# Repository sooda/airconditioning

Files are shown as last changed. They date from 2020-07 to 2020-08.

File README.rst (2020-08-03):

my air conditioning adapters
============================

You probably won't need any of these highly specific 3D print designs.

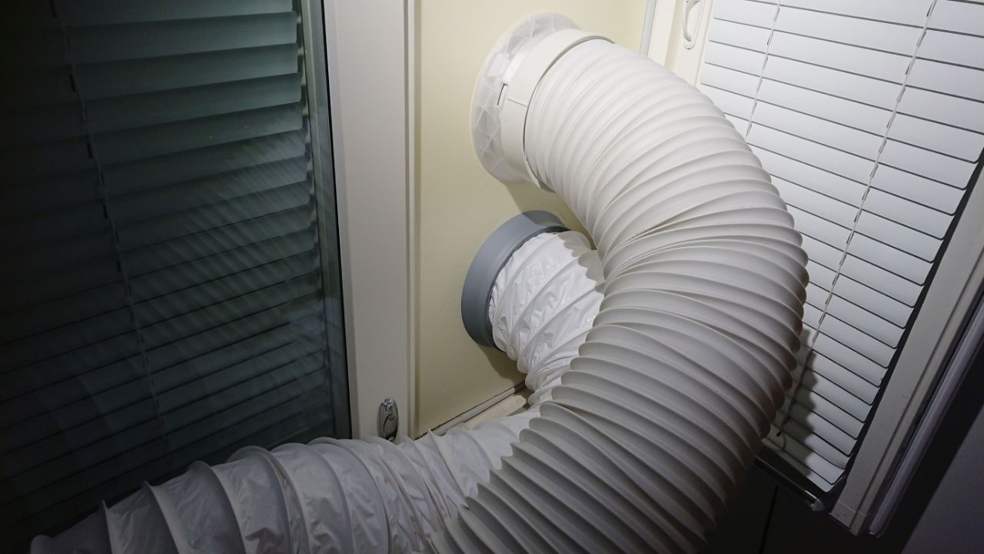
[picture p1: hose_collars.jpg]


Procedure
---------

0. Suffer from 27+ °C indoors
1. Overthink those poor portable AC units
2. Buy one that seems decent from the internets
3. The delivery service destroys it
4. All decent ones are sold out because it's spring already
5. Get angry, lose interest
6. Buy a cheapo model from the nearest hardware store
7. Overthink a window attachment for its hose(s), buy some XPS sheet for a tight window fit
8. Hack up an intake hose connection out of cardboard and hose stuff from a hardware store
9. 3D print neat attachments for the hose ends for easier use
10. Document it so I'll remember later what has happened

TODO
~~~~

* Optimize: find where air is leaking, insulate the hoses, etc.
* Finish the outdoor parts to keep rain out.
* Hack up something on the cool air vent to shoot the air at an adjustable angle so the machine could be placed more conveniently in a corner.
* Buy a house or something to avoid this workaround shit in the first place.

exhaust_adapter.scad
--------------------

Adapts the exhaust hose end to the window panel.
The exhaust hose has proper plastic attachments on obviously the machine end and also on the window end, although the box didn't include any information on how to use that.

I've fitted a mosquito net separately on the whole window, so this piece doesn't have any filter things for when the device is off and no air is moving.
The inner pipe is supposed to be glued to a flap mechanism that doesn't exist yet to protect from heavy rain.
I'll get to that later.

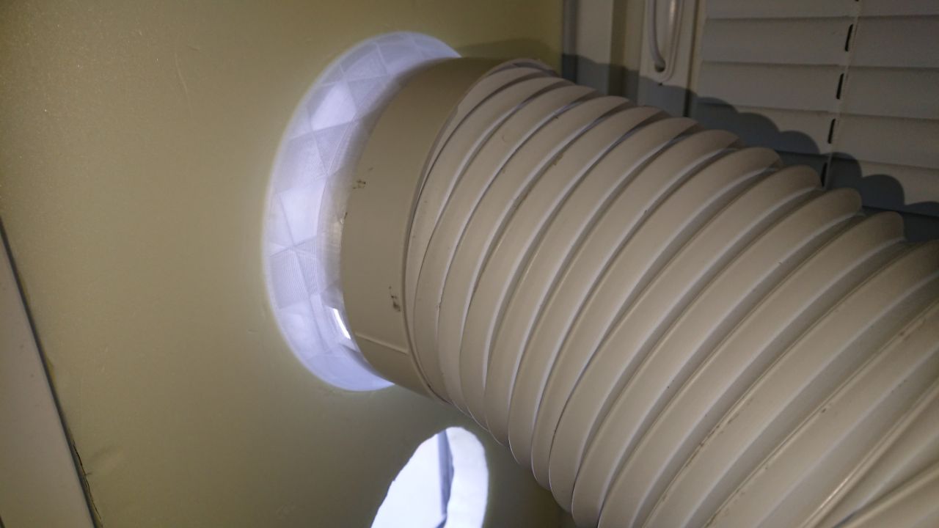
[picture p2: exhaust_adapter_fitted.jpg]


input_screw_flange.scad
-----------------------

Adapts the DIY input hose to the the box thing that's around the large rectangular intake of the hot side.
The intake grille is way too big for 3d printing but easy-shaped so that just a cardboard adapter to another adapter is good enough.
The hose screws inside this printed part that is then attached on the cardboard box.

Fortunately the device appears to have separate air circuits for the hot side and the cold side, so it's possible to add an input hose to match the hot output.
This way the device at least won't unbalance the indoor air pressure and airflow so much and won't heat and push out the cooled indoor air.
I haven't measured whether this makes a big difference.

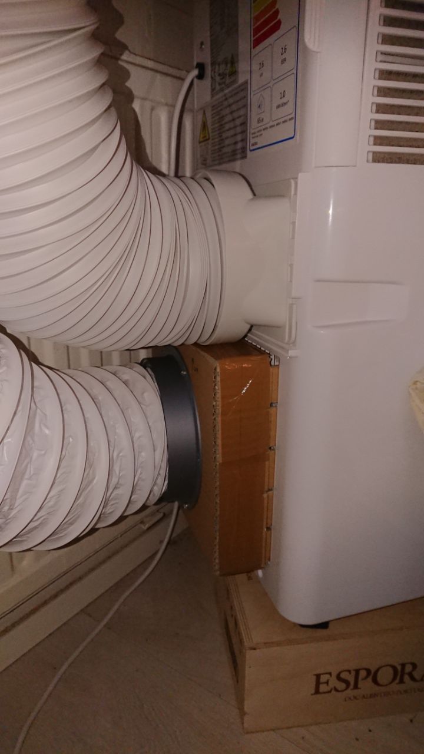
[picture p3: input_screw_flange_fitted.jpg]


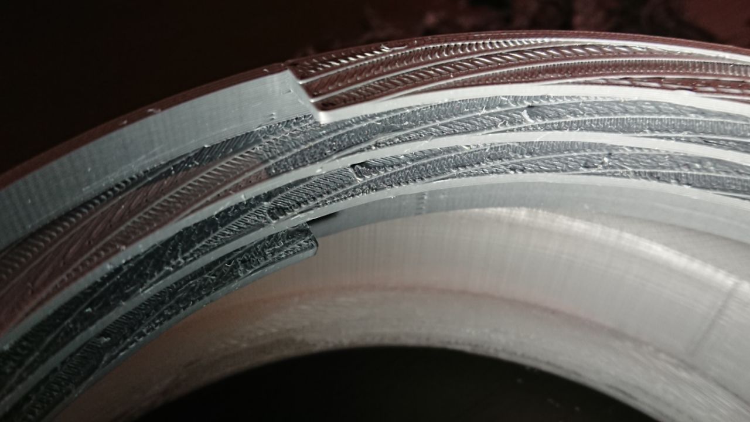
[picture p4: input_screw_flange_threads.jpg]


input_hose_collar.scad
----------------------

Like the side on the machine input, this screws on the `biltema hose`_ but on the other end that goes on the window panel like the exhaust adapter.
This is not an extra adapter but goes directly on the window panel.
The inner part is again supposed to be glued to a flap mechanism or something, see the exhaust_adapter story.

.. _biltema hose: https://www.biltema.fi/rakentaminen/lvi/ilmanvaihto/ilmanvaihtoletkut/ilmanvaihtoletku-2000031439

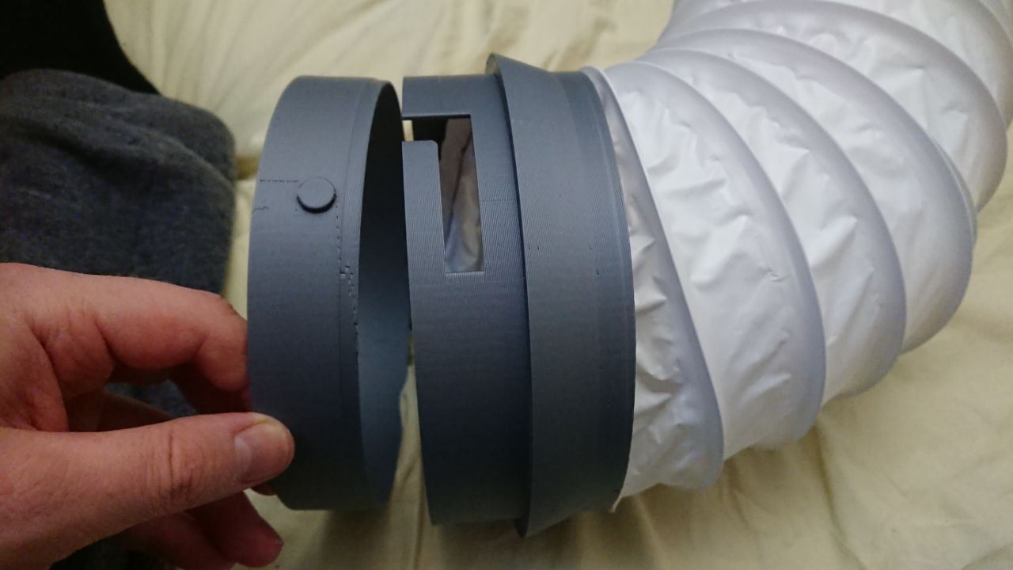
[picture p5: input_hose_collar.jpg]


The device
----------

Bought from here: https://www.motonet.fi/fi/tuote/789629/Ilmastointilaite-siirrettava-9000-BTU

It's apparently Chinanordica A007G-09C: http://chinanordica.com/portableairconditioner_215.html

Kinda works but it's terrible.

License
-------

`CC-BY-SA 4.0 <https://creativecommons.org/licenses/by-sa/4.0/>`_ - tl;dr: share and adapt, just say where it's from and what you changed, and keep these conditions.

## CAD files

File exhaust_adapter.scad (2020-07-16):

// the connector adapter
render_hose_part = true;
// use this to check alignment
hose_translucent = true;
// the rain filter
render_outdoor_part = true;
// render the full pipe, turn off to see the lock parts
show_body = true;
// model the tooth notch receptable as cylinder geometry, not cube
accurate_tooth = true;

// measurements of the existing hose attachment:

// the collar where the hose screws into
outer_length = 30;
// outermost dimension
outer_diameter = 152; // 151...152.8
// not inside the connector, but the outer part of the smaller bit that goes inside this adapter
inner_diameter = outer_diameter - 2 * 4.4;
// from the outer bit to the lock tooth lip with some margin
lock_tooth_notch_depth = 2.2;
// the tooth is a slope, this is the nonzero end measured against inner_diameter
lock_tooth_thickness = 1.7;
// some margin so the locks don't need to be pushed all the way
lock_tooth_ease = 0.5 * lock_tooth_thickness;
// lock tooth size in the radial direction
tooth_width = 20;
// basically pipe_overlap - lock_tooth_notch_depth
tooth_height = 10;
// length of the smaller bit
pipe_overlap = 12.6;

// general body sizes:

// this adapter goes to a panel that replaces one of my window frames for the summer
// the previous hack had a 16cm hose and this goes to the same cutout
panel_hole_diameter = 160;
// the pipe goes through the panel
panel_thickness = 30;
// a flange bit to keep the part close to the panel; "radius" dimension
collar_width = 7;
// the collar bit aesthetic length between outer_diameter and panel_hole_diameter; like this for symmetry
collar_length = outer_length - pipe_overlap;
// before the collar, goes around the pipe_overlap bit with inner_diameter
// XXX: this is a bad name
pipe_full_length = pipe_overlap;//outer_length - collar_length;

// the "outdoor" side part that will have flaps of some sort to block rain:

// how much to reserve outside the panel hole to glue to the actual flap mechanism
flappipe_joinlength = 2;
// this goes inside the hose attachment adapter
flappipe_length = panel_thickness + flappipe_joinlength;
// doesn't need to be very heavy, just smooth. XXX: quantize according to your 3d printer nozzle
flappipe_thickness = 4;
// the inner diameter is consistent throughout the parts
flappipe_outer_diameter = inner_diameter + 2 * flappipe_thickness;

// the two pipes lock together slightly to ensure consistency:

// groove depth into the flap pipe. XXX: quantize according to your 3d printer nozzle
lockring_depth = 2;
// the two parts will rotate and clip on together; this is measured against the indoor end of the outdoor pipe
lockring_length = 2;
// length and some extra slop; XXX: quantize
lockring_groove_clearance = 0.2;
// consistent dimensions just with slop
lockring_groove = lockring_length + lockring_groove_clearance;
// how far the snap knob is from the end of the latch head, measured along the inner_diameter surface
lockblob_distance = 8;
// multiplier for how much bigger the notch is than the blob
lockblob_clearance = 1.05;
// how long the lock mechanism is around the cylinder surface
lockring_length_angle = 45;

// debug and dev stuff:

// use this to lift the inner bit out for debugging
parts_shift = 0;
//parts_shift = 1.5 * panel_thickness;

// angle for visual debugging of the lock knob
lockviz_delta = 0;

// fight the z with 1% the feature size
eps = 0.01;
// very long
inf = 1000;

include <utils.scad>

// a positive geometry to reduce from the indoor pipe body
module lock_notch_receptable() {
	if(!accurate_tooth) {
		// fast mode
		translate([0, -tooth_width / 2, 0]) {
			translate([0, 0, lock_tooth_notch_depth]) {
				// the hole bit
				cube([outer_diameter / 2 + eps, tooth_width, tooth_height]);
			}
			translate([0, 0, -eps]) {
				// the ease bit measured from the floor of the pipe
				cube([inner_diameter / 2 + lock_tooth_ease + eps, tooth_width, tooth_height]);
			}
		}
	} else {
		// this way makes the preview extremely slow, and buggy depending on the view angle and the
		// below choices, or makes the whole design disappear. The render will be fine though. I'll
		// debug why some day. Might be a bug/feature with the huge boxes in the pizza pipe.
		// Swap the inner true to false to use pizza pipes and the whole preview vanishes.

		if (true) translate([0, 0, lock_tooth_notch_depth]) {
			// the hole bit
			if (true) {
				pizzaslice(tooth_height,
					outer_diameter / 2 + eps,
					angle_for_circumference(tooth_width, inner_diameter / 2));
			} else {
				pizzapipe(tooth_height,
					outer_diameter / 2 + eps,
					inner_diameter / 2 - eps,
					angle_for_circumference(tooth_width, inner_diameter / 2));
			}
		}
		if (true) translate([0, 0, -eps]) {
			// the ease bit measured from the floor of the pipe
			if (true) {
				pizzaslice(lock_tooth_notch_depth + 2*eps,
					inner_diameter / 2 + lock_tooth_ease,
					angle_for_circumference(tooth_width, inner_diameter / 2));
			} else {
				pizzapipe(lock_tooth_notch_depth + 2*eps,
					inner_diameter / 2 + lock_tooth_ease,
					inner_diameter / 2 - eps,
					angle_for_circumference(tooth_width, inner_diameter / 2));
			}
		}
	}
}

// the indoor side of the pipe locking mechanism
module latchpin(angle) {
	translate([0, 0, lockring_length + lockring_groove_clearance / 2]) {
		// rotate away from the stop bit
		rotate([0, 0, angle - angle_for_circumference(lockring_length, inner_diameter / 2)]) {
			difference() {
				// the pin itself. The added epsilon gets rid of flickering that supposedly comes
				// from the pin pizza CSGing exactly against the pipe surface; although it's a
				// separate operation, it gets visible and might cause some nasty zero-size
				// geometry? Again, it would be nice to be able to constraint this on exactly the
				// inner surface, but here we are with floating point math.
				pizzapipe(lockring_length,
						flappipe_outer_diameter / 2 + eps,
						flappipe_outer_diameter / 2 - lockring_depth,
						lockring_length_angle);
				// the lock notch cut away from the pin
				rotate([0, 0, lockring_length_angle
						- angle_for_circumference(lockblob_distance - lockring_length, inner_diameter / 2)]) {
					// FIXME: make some of the geometry common for the pin and the groove
					translate([flappipe_outer_diameter / 2 - lockring_depth, 0, -eps]) {
						cylinder(h=lockring_length + 2*eps,
							r=lockblob_clearance * lockring_depth / 2,
							$fs=0.1);
					}
				}
			}
		}
	}
}

// the outdoor side of the pipe locking mechanism
module lockslider(angle) {
	translate([0, 0, eps]) // fuck that flicker and wrong colors on surfaces
	rotate([0, 0, angle]) {
		// the slider including the end stop
		difference() {
			// yes, +eps. This ensures the surface goes inside the other
			pizzapipe(lockring_length + lockring_groove + eps,
					flappipe_outer_diameter / 2,
					flappipe_outer_diameter / 2 - lockring_depth - eps,
					lockring_length_angle);
			// the pin groove is a bit higher and offset for the stop
			rotate([0, 0, -angle_for_circumference(lockring_length, inner_diameter / 2)]) {
				translate([0, 0, lockring_length]) {
					pizzapipe(lockring_groove + 2 * eps,
						flappipe_outer_diameter / 2 + eps,
						flappipe_outer_diameter / 2 - lockring_depth - 2 * eps,
						lockring_length_angle);
				}
			}
		}
		// the lock blob
		rotate([0, 0, lockring_length_angle
				- angle_for_circumference(lockblob_distance, inner_diameter / 2)]) {
			translate([flappipe_outer_diameter / 2 - lockring_depth, 0, lockring_length]) {
				cylinder(h=lockring_groove, r=lockring_depth / 2, $fs=0.1);
			}
		}
	}
}

module hose_part() {
	if (show_body) {
		color("yellow") {
			// Change this difference to union to debug the slow rendering
			difference() {
				pipe(pipe_full_length, outer_diameter / 2, inner_diameter / 2);
				render()
				union() {
					lock_notch_receptable();
					rotate([0, 0, 360/3])
						lock_notch_receptable();
					rotate([0, 0, 2*360/3])
						lock_notch_receptable();
				}
			}
			// the collar goes from the interface bit to the face of the panel.
			// why does the epsilon trick not help here with that hot pixel flicker on the inner face?
			translate([0, 0, pipe_full_length - eps])
				pipe_outer_bevel(eps + collar_length,
					outer_diameter / 2,
					panel_hole_diameter / 2 + collar_width,
					inner_diameter / 2);
			// the bit inside the panel. The inner diameter grabs to the outdoor pipe
			translate([0, 0, pipe_full_length + collar_length - eps])
				pipe(eps + panel_thickness,
					panel_hole_diameter / 2,
					flappipe_outer_diameter / 2);
		}
	}

	color("blue") {
		// note: no stop ring needed - the panel part is larger inside to fit the outdoor pipe
		translate([0, 0, pipe_full_length + collar_length]) {
			// the latch pins hover above the stop ring
			latchpin(0);
			latchpin(180);
		}
	}
}
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

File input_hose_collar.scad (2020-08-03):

// #87-3828 152mm 3m air hose:
// https://www.biltema.fi/rakentaminen/lvi/ilmanvaihto/ilmanvaihtoletkut/ilmanvaihtoletku-2000031439

// This piece goes directly through the window panel! The two-piece construction on the exhaust hose
// is just to match and reuse the existing collar on it.

// the collar itself
render_hose_part = true;
// use this to check alignment and to debug the threads
hose_translucent = true;
// the rain filter
render_outdoor_part = true;

// outmost hose dimensions, by chance it's the same as the outer diameter of the exhaust hose collar
hose_outer_diameter = 152;
// gap between the hose and the inner face of the pipe
thread_tolerance = 2;
// 160 mm matches the other window panel hole and thickness becomes 2 mm
outer_diameter = 160;

// the outer dimension is more important than this one, although do mind this as well
thickness = (outer_diameter - hose_outer_diameter) / 2 - thread_tolerance;

// this much overlap with the hose
visible_length = 30;

// the pipe goes through the panel and an outdoor part aligns with this inner face
panel_thickness = 30;
// a flange bit to keep the part close to the panel; "radius" dimension
collar_width = 7;
// The collar overlaps with the threaded bit and is this long before reaching the window panel face. Some flat is left for better finger grip
collar_length = 20;

// keep this less than ~17mm
thread_depth = 8;
// thread face dimension on the visible (hose) side. A trapezoidal cross section may cause your slicer to generate a more complex thread surface that will slide easier but is a pain to clean up from the supports.
thread_thickness_side = 1.5;
// thread face dimension on the pipe side
thread_thickness_body = 3;
// spacing between facing thread faces to contribute to the lead aka pitch, compare against the hose flex
thread_spacing = 4;
thread_lead = thread_thickness_body + thread_spacing;
// Three shall be the number thou shalt count, and the number of the counting shall be three.
thread_revolutions = 3;

thread_length = thread_lead * thread_revolutions;

inner_diameter = hose_outer_diameter + 2 * thread_tolerance;
thread_inner_diameter = inner_diameter - 2 * thread_depth;

// how much to reserve outside the panel hole to glue to the actual flap mechanism
flappipe_joinlength = 2;
// this goes inside the hose attachment adapter
flappipe_length = panel_thickness + flappipe_joinlength;
// doesn't need to be very heavy, just smooth
flappipe_thickness = 2;
// there has to be some slop so the flap pipe that goes inside can be inserted smoothly
flappipe_tolerance = 0.2;
// the inner diameter is NOT consistent throughout the parts because the outer body is so thin
flappipe_outer_diameter = inner_diameter - 2 * flappipe_tolerance;
flappipe_inner_diameter = flappipe_outer_diameter - 2 * flappipe_thickness;
// how much until full thickness
flappipe_bevel_length = 10;
// how much to take off from flappipe_thickness
flappipe_bevel_thickness = 2;

// the knob to join the indoor and outdoor parts is situated in the outdoor border and is this big
lockknob_diameter = 10;
// insertion depth
lockslot_depth = 20;
// "tangential" length along the side
lockslot_length = 30;
// total slop, not in "both sides" like the others here
lockslot_clearance = 0.1;
// "negative" clearance on the edge where the locking action should happen. This tiny fit blob is likely unnecessary, but let's see what happens with it.
lockslot_tightfit = 0.2;

// use this to lift the inner bit out for debugging
parts_shift = 0;
// angle for visual debugging of the lock knob
lockviz_delta = 0;

// fight the z with 1% the feature size
eps = 0.01;
// very long
inf = 1000;

include <utils.scad>

module helix() {
	//     body
	//    ______
	// ^ \      /
	// y  \____/
	// |   side
	// +--x> (not to scale)
	// ccw
	cross_section = [
		[(thread_thickness_body - thread_thickness_side) / 2, 0],
		[(thread_thickness_body - thread_thickness_side) / 2 + thread_thickness_side, 0],
		[thread_thickness_body, thread_depth],
		[0, thread_depth],
	];
	translate([0, 0, 0]) {
		difference() {
			rotate([0, -90, 0]) {
				thread_extrude(cross_section,
					inner_diameter / 2 - thread_depth + 0.05, // XXX: beware of gaps, depends on face count
					thread_length, thread_lead, 360/2);
			}
			// Make the thread tip less blunt by cutting off a slice at an angle. The cut size is
			// chosen for aesthetic reasons to align smoothly to the thread's inner face. The cut
			// begins from the very end and meets the inner face in parallel, forming a 90 degree
			// angle with a line that goes towards the center.
			//
			// This messes up the preview pretty badly depending on the view angle, no clue what
			// that's about.
			//
			// This is also not super general, might not work with very tight threads due to the cut
			// bit being aligned to the very top. These threads are not parallel to the cube face.
			translate([0, 0, -thread_spacing / 2]) {
				// Thanks, Pythagoras
				cut_length = sqrt(pow(inner_diameter / 2, 2) - pow(thread_inner_diameter / 2, 2));
				// law of sines
				cut_triangle_angle = asin(cut_length / (inner_diameter / 2));
				rotate([0, 0, cut_triangle_angle]) {
					cube([
						thread_inner_diameter / 2 + eps,
						thread_inner_diameter / 2,
						thread_thickness_body + thread_spacing]
					);
				}
			}
		}
	}
}

module lockknob_receptable(angle) {
	lockknob_ang = angle_for_circumference(lockknob_diameter + 2 * lockslot_clearance, inner_diameter / 2);
	lockslot_length_ang = angle_for_circumference(lockslot_length, inner_diameter / 2);
	rotate([0, 0, angle - lockknob_ang / 2]) {
		// cut down for the insertion slot
		pizzaslice(lockslot_depth, inf, lockknob_ang);
		difference() {
			// cut along the main cylinder for rotation, ccw for cw locking
			pizzaslice(lockknob_diameter + 2 * lockslot_clearance, inf, -(lockknob_ang + lockslot_length_ang));
			// add back the tiny lock blob. This is not exactly the right position at the end, but
			// doesn't matter, it's close enough, or might not even exist depending on your print slicing.
			rotate([0, 0, -(lockslot_length_ang + 0.25 * lockknob_ang)])
				rotate([0, 90, 0])
					cylinder(h=2*inf, r=lockslot_clearance + lockslot_tightfit, $fn=30);
		}
	}
}

module hose_body() {
	difference() {
		pipe(visible_length + panel_thickness, outer_diameter / 2, inner_diameter / 2);
		translate([0, 0, visible_length + panel_thickness - lockslot_depth + eps]) {
			lockknob_receptable(0);
			lockknob_receptable(180);
		}
	}
	translate([0, 0, visible_length - collar_length]) {
		pipe_outer_bevel(collar_length,
			outer_diameter / 2,
			outer_diameter / 2 + collar_width,
			inner_diameter / 2 + eps);
	}
}

module threaded_body() {
	if (hose_translucent) {
		#hose_body();
	} else {
		hose_body();
	}
	helix();
}

module lockknob(ang) {
	rotate([0, 0, ang]) {
		translate([flappipe_inner_diameter / 2, 0, 0])
		rotate([0, 90, 0]) {
			// XXX: should be a half cone maybe
			cylinder(flappipe_thickness + thickness, r=lockknob_diameter / 2, $fs=0.1);
		}
	}
}

module outdoor_part() {
	// this part is positioned exactly at the panel face
	translate([0, 0, visible_length]) {
		if (true) {
			color("green") {
				difference() {
					pipe(flappipe_length,
						flappipe_outer_diameter / 2,
						flappipe_inner_diameter / 2);
					translate([0, 0, -eps])
					pipe_inner_bevel(flappipe_bevel_length,
						flappipe_outer_diameter / 2 + eps,
						flappipe_outer_diameter / 2 - flappipe_bevel_thickness,
						flappipe_outer_diameter / 2
						);
				}
			}
		}
		color("magenta") {
			translate([0, 0, panel_thickness - 3 * lockknob_diameter / 2]) {
				lockknob(0);
				lockknob(180);
			}
		}
	}
}

module hose_collar() {
	if (render_hose_part)
		threaded_body();
	if (render_outdoor_part)
	translate([0, 0, parts_shift])
		rotate([0, 0, lockviz_delta])
			outdoor_part();
}

hose_collar();

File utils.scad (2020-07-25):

// cylinder minus inner cylinder
module pipe(h, outer_r, inner_r) {
	difference() {
		cylinder(h=h, r=outer_r, $fn=180);
		translate([0, 0, -eps])
			cylinder(h=h+2*eps, r=inner_r, $fn=180);
	}
}

// cone minus inner cylinder
module pipe_outer_bevel(h, outer_r1, outer_r2, inner_r) {
	difference() {
		cylinder(h=h, r1=outer_r1, r2=outer_r2, $fn=180);
		translate([0, 0, -eps])
			cylinder(h=h+2*eps, r=inner_r, $fn=180);
	}
}

// cylinder minus inner cone
module pipe_inner_bevel(h, outer_r, inner_r1, inner_r2) {
	difference() {
		cylinder(h=h, r=outer_r, $fn=180);
		translate([0, 0, -eps])
			cylinder(h=h+2*eps, r1=inner_r1, r2=inner_r2, $fn=180);
	}
}

// a pizza slice is under 90 degrees big and exists in the first quadant, lies on top of the x axis
module pizzamask(angle) {
	intersection() {
		// first quadrant
		translate([0, 0, -inf/2])
			cube([inf, inf, inf]);

		// from x axis counterclockwise
		rotate([0, 0, angle - 90])
			translate([0, 0, -inf/2])
				cube([inf, inf, inf]);
	}
}

// a difference of two of these may glitch in the outer face no matter how big epsilon,
// depending on your gpu driver version?? (in preview mode only)
module pizzapipe(h, outer_r, inner_r, angle) {
	render() // avoid exponential growth
	intersection() {
		pipe(h, outer_r, inner_r);
		pizzamask(angle);
	}
}

module pizzaslice(h, r, angle) {
	render() { // avoid exponential growth
		if (angle < 0) {
			// ccw
			rotate([0, 0, angle]) {
				intersection() {
					cylinder(h=h, r=r, $fn=180);
					pizzamask(-angle + eps);
				}
			}
		} else {
			// cw
			intersection() {
				cylinder(h=h, r=r, $fn=180);
				pizzamask(angle);
			}
		}
	}
}

// for matching pizza slice angles with mm dimensions
// a/360 * 2*pi*r = s
function angle_for_circumference(s, r) = 180 / PI * s / r;

// along x axis, right hand rule
function thread_track_point(r, lead, a) = [
	a / 360 * lead,
	r * cos(a),
	r * sin(a),
];

function thread_track(r, lead, xs) = [
	for (x=xs) thread_track_point(r, lead, x)
];

function rz(a) = [
	[1,      0,       0],
	[0, cos(a), -sin(a)],
	[0, sin(a),  cos(a)]
];

// face_vertices shall be counterclockwise, as it'll be the underside: when
// looking from the top, this grows initially towards the viewer.
module thread_extrude(face_vertices, r, length, lead, rev_resolution) {
	face_size = len(face_vertices);
	revolutions = length / lead;
	// the track with n volume sections has n+1 face segments
	segments = rev_resolution * revolutions + 1;
	//track = thread_track(10, 360, [0:n-1]);
	pts = [
		for (i=[0:segments-1])
			for (p = face_vertices)
				rz(i / rev_resolution * 360) * [p[0], p[1], 0]
						+ thread_track_point(r, lead, i / rev_resolution * 360)
	];

	front_face = [[for (i=[0:face_size-1]) i]];
	back_face = [[for (i=[0:face_size-1]) len(pts) - 1 - i]];
	inner_faces = [
		for (begin_slice = [0:segments-2])
			for (begin_vert = [0:face_size-1]) [
				 begin_slice      * face_size + begin_vert,
				(begin_slice + 1) * face_size + begin_vert,
				(begin_slice + 1) * face_size + (begin_vert + 1) % face_size,
				 begin_slice      * face_size + (begin_vert + 1) % face_size
			]
	];
	faces = concat(front_face, inner_faces, back_face);
	polyhedron(pts, faces);
}

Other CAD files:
input_screw_flange.scad

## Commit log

2020-06-30 initial commit with dimensions and template
    This should fit the connector. The window part does not exist yet.
    [exhaust_adapter.scad]
2020-06-30 pipe it through the panel
    Preparing for a low pressure drop exhaust grille, a 160mm pipe through
    the window frame adapter panel thing. I wonder how the airfoil bits
    should be designed for efficiency. The mosquito net probably kills the
    major part already though.
    [exhaust_adapter.scad]
2020-06-30 collar/flange/something bit to keep this in place
    Something similar to come in the other side too perhaps? Should this
    screw on the panel or just be a tight fit?
    [exhaust_adapter.scad]
2020-07-01 planning on the outdoor side's attachment
    The flaps-side bit shall be a thin pipe to go inside the major body.
    Locking together might happen with a simple mechanism inspired by a dslr
    lens hood.
    [exhaust_adapter.scad]
2020-07-02 receptable for the lock groove
    The other side of the lock mechanism is a pin with a matching slot. Also
    pull the groove parts in so they're properly inside the inner pipe.
    [exhaust_adapter.scad]
2020-07-03 depth stop ring for the inner pipe
    Measurements must be all off-by-one or something at this point. The
    structure is nice enough for now.
    [exhaust_adapter.scad]
2020-07-04 better documentation, restructure
    Shuffle stuff around and rename identifiers for consistency, or else
    I'll go mad in just a day forgetting this. Need to digitize the sketches
    on paper sooner or later, too. Making the outer bit translucent is very
    useful for debugging.
    The lock clearance doesn't seem consistent... A real constraint-based
    CAD with an understanding of surfaces would be so much better for this.
    [exhaust_adapter.scad]
2020-07-04 rotate the whole outer part for visualization
    The latch pins shall be consistent wrt. the whole body
    [exhaust_adapter.scad]
2020-07-05 make outdoor part consistent with inner diameter
    This way the pipe to go inside the panel has a larger inner diameter and
    the "stop ring" appears naturally when the outdoor pipe fills that void.
    [exhaust_adapter.scad]
2020-07-05 careful with epsilons
    Those darn flickering surfaces haunt this design. Always do the epsilon
    on both sides: when translating -eps the size must be inflated by 2*eps.
    [exhaust_adapter.scad]
2020-07-05 so sick of these epsilons
    Preview rendering artifacts make some stuff unusable without epsilons
    because the real render is too slow for iterative development. Some
    flickering still occurs between the pipe segments even with epsilons,
    but it's not a whole surface in the wrong place - just a few pixels.
    [exhaust_adapter.scad]
2020-07-05 give flappipe_outer_diameter a name
    this is the surface between the indoor part and the panel pipe
    [exhaust_adapter.scad]
2020-07-05 make sure the groove fits
    Double checks and clarifications for how the groove is measured. The
    groove with its clearance is the gap where the lock pin goes. The
    outdoor surface shall align exactly with the panel indoor surface.
    [exhaust_adapter.scad]
2020-07-05 model the tooth holes properly but slowly
    So why this is orders of magnitude slower? Something to do with the
    subtraction but really openscad breaks way too easily and it's not
    trivial to figure out what's hogging the cpu all of a sudden.
    [exhaust_adapter.scad]
2020-07-05 from ~6000 to 65 CSG elements
    Prune the normalization tree with a careful render() for the lock notch
    geometry. Those intersecting sectors apparently cause the exponential
    explosion; see commit c810264.
    A general render() in the pizzapipe/pizzaslice ops cause additional z
    fighting.
    https://en.wikibooks.org/wiki/OpenSCAD_User_Manual/FAQ#Why_is_the_preview_so_slow.3F
    "This is hard to explain, but in essence, having intersections as the
    negative objects in difference is expensive"
    Just some thousands of objects doesn't seem so huge though. Perhaps
    someone should fix the immediate mode rendering.
    [exhaust_adapter.scad]
2020-07-05 render also the pizza pipe and slice alreadyo
    Found the cause of the z fighting. It wasn't there before render(). This
    halves the tree size.
    [exhaust_adapter.scad]
2020-07-06 final print settings of v1
    Forgot to save these but the printed object has these dimensions. Also,
    the inner ring is obviously a very tight fit; the lock ring is not even
    needed. Should probably reduce the size by 0.1 mm or so for easier use.
    [exhaust_adapter.scad]
2020-07-14 extract common geometry stuff to utils
    These might be needed with other components as well.
    [exhaust_adapter.scad, utils.scad]
2020-07-14 initial commit for device-side input adapter
    The machine itself does not support an input hose for the hot side but
    it's easily hacked with a cardboard box and some adapters. This will be
    the adapter that goes to the box on the machine's hot-side input hole.
    I've got an annoying hose there already. The better hose I've got is too
    different to fit the existing bits and the shop doesn't stock a matching
    adapter.
    Hey openscad, why no combination of a linear extrude and a rotate
    extrude? Apparently people have made screw libs already but let's make a
    custom one to have some fun. The linear extrude twists in the wrong axis
    for stuff like this and rotate extrude doesn't support z translation.
    [input_screw_flange.scad]
2020-07-14 some screw planning
    Openscad doesn't include a good way to do screw-like things, so let's
    roll our own with a single polyhedron. Coming up with a diy
    rotate_extrude() with extra support to translate along the way would be
    a natural way to do this, or linear_extrude() with the cross section in
    a different angle. Overdoing a general operation to use an extrusion
    track and a cross section must be perfect. Unfortunately functions
    aren't first-class things in the language so a vertex transform function
    won't do.
    [input_screw_flange.scad]
2020-07-14 make the screw work, looking good already
    This appears to work; smoke tested with small resolutions (about 3). Not
    general yet, will fix that later.
    [input_screw_flange.scad]
2020-07-14 move the screw to its proper place
    [input_screw_flange.scad]
2020-07-14 repair fillet
    The rotate-extruded bit has to match the fillet circle accurately enough
    to avoid irregularities far from the vertices.
    [input_screw_flange.scad]
2020-07-14 mounty mcmountface
    This shall be screwed to the cardboard box that is the bigger adapter
    [input_screw_flange.scad]
2020-07-14 bugfix outer diameter
    reference the inner surface with the thickness because tolerance
    [input_screw_flange.scad]
2020-07-14 fix screw winding
    The back face needs a mirrored orientation to be consistent.
    Fix docs: the given face / cross section has to be counterclockwise
    because the screw is constructed that way: when looking at the section
    flat from the z axis, the "back side" of it is seen as it grows that way
    with the right hand rule.
    [input_screw_flange.scad]
2020-07-16 some epsilonification
    now it's no longer invalid.
    This version got printed. Needs improvement on the threads.
    [input_screw_flange.scad]
2020-07-16 fix screw cross section
    Some measurements were of course mirrored accidentally. Use the correct
    ones.
    [input_screw_flange.scad]
2020-07-16 better dimensions for the next input piece version
    - the fit is still pretty tight; add a millimeter to tolerance radius
    - move the mounting holes further apart from the fillet
    - increase mounting hole size by 0.2 mm
    - use six mounting holes just in case as this is such a big object
    - increase the gap between screw surfaces to 4 mm for easier support
    structure cleanup and increased tolerance because the previous was a
    brainfart anyway
    [input_screw_flange.scad]
2020-07-16 readme and stuff for historical reference
    this is easier to share via github than irc and scp
    [exhaust_adapter.scad]
2020-07-23 Final docs on the input flange adapter
    The flanged nut bit for the input hose is now printed. It's not perfect
    but it's fine.
    The threads were a bit tricky to clean up from support material (which
    probably was necessary due to the significant overhang). An even
    side/body thickness for the threads would have mostly prevented this,
    but it would have caused perpendicular steps on the printed layers that
    might interfere with the ease of installation. Probably not though if
    the steel wire inside the hose would be just twisted a bit from the end.
    [input_screw_flange.scad]
2020-07-24 document the nasty thread end for next version
    This particular piece will likely never get a next version, but the
    other end of the hose will have a similar thread. Reminder to update.
    [input_screw_flange.scad]
2020-07-25 s/screw/thread/ in most places
    more exact vocabulary is more exact
    [input_screw_flange.scad]
2020-07-25 make the thread tip less blunt for easier install
    This does not matter anymore for the existing object I have, but the
    other end of the hose will receive the same treatment. Figure out a nice
    triangle from the end tip on the outer thread surface to the side of the
    inner thread surface to meet it tangentially. Use the triangle to cut a
    bit out of the threads.
    Constructing the threads with this "ease-in" built in would be more
    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
    [input_screw_flange.scad]
2020-07-25 move the thread extrusion to utils
    [input_screw_flange.scad, utils.scad]
2020-07-25 initial input hose collar object
    This goes to the other end of the input hose, facing the window panel.
    Now there's just this, not one for the hose and one for the panel.
    TODO the outdoor part and locking mechanism. Maybe a manual knob to lock
    the flaps for rain because they need to angle inwards along the airflow.
    [input_hose_collar.scad]
2020-07-25 support negative angles for pizzaslice()
    It's useful to turn the other way around with just a negation
    [utils.scad]
2020-07-25 add outdoor pipe and lock knob for input collar
    Add a pipe to go inside the indoor part to be eventually glued to a flap
    mechanism of some sort, like with the exhaust hose.
    This time the "locking" mechanism is much bigger, somewhat different in
    orientation, and situated near the outdoor side.
    [input_hose_collar.scad]
2020-08-03 the input hose collar is printed; add todo
    The clearance with everything is great, the rough supports with no
    interface layers were easy to remove, the tiny lock blob doesn't exist,
    the hose end isn't perfect so it starts to screw on with extra effort.
    [input_hose_collar.scad]
